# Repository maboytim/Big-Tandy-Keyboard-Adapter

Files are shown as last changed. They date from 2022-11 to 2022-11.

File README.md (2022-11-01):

# Big-Tandy-Keyboard-Adapter
PS2 keyboard adapter for 'Big Tandy' computers - Models II, 12, 16, 16B, and 6000.

The keyboard allows you to use a PS2 keyboard with your 'Big Tandy' computer.  There are three versions:

### "A" Version
The A version is for the Models II and 16.  These models have the keyboard cable attached to the computer.  The adapter connects to the end of the cable and the PS2 keyboard to the adapter.

### "B" Version
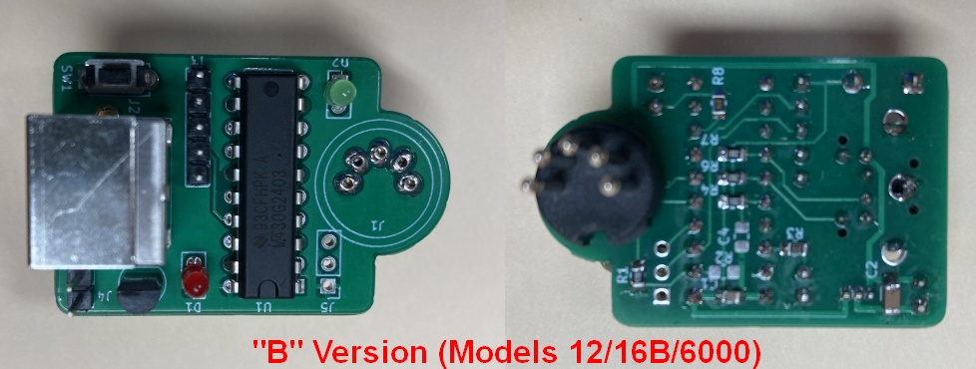
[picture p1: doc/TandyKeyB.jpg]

The B version is for the Models 12, 16B, and 6000.  These models have the keyboard cable attached to the computer.  The adapter plugs directly into the keyboard plug on the front of the computer and the PS2 keyboard into the adapter.

### "AB" Version (universal)
The AB version is for all models.  It has a 5-pin header to connect a pigtail cable.  A pigtail with a male DIN5 connector for Models 12/16B/6000 or a pigtail with a female DIN5 connector for Models II/16.  The pinout differences are also accounted for in the pigtail cable.

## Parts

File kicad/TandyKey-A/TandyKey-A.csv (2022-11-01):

Source: | C:\Users\matt\Documents\KiCad\6.0\TRS-80-M3-KEY\TRS-80-M3-KEY.kicad_sch
Date: | 8/21/2022 6:23:56 AM
Tool: | Eeschema (6.0.0)
Generator: | C:\Program Files\KiCad\6.0\bin\scripting\plugins/bom_csv_grouped_by_value.py
Component Count: | 32
Individual Components:
Item | Qty | Reference(s) | Value | LibPart | Footprint | Datasheet
 |  | C1 | 0.1uF | Device:C | Capacitor_SMD:C_0805_2012Metric_Pad1.18x1.45mm_HandSolder | ~
 |  | C2 | 0.1uF | Device:C | Capacitor_SMD:C_0805_2012Metric_Pad1.18x1.45mm_HandSolder | ~
 |  | C3 | 0.1uF | Device:C | Capacitor_SMD:C_0805_2012Metric_Pad1.18x1.45mm_HandSolder | ~
 |  | C6 | 10u | Device:C_Polarized | Capacitor_SMD:C_1206_3216Metric_Pad1.33x1.80mm_HandSolder | ~
 |  | C7 | 10u | Device:C_Polarized | Capacitor_SMD:C_1206_3216Metric_Pad1.33x1.80mm_HandSolder | ~
 |  | C8 | 10u | Device:C_Polarized | Capacitor_SMD:C_1206_3216Metric_Pad1.33x1.80mm_HandSolder | ~
 |  | H1 | MountingHole | Mechanical:MountingHole | MountingHole:MountingHole_3mm_Pad_Via | ~
 |  | H2 | MountingHole | Mechanical:MountingHole | MountingHole:MountingHole_3mm_Pad_Via | ~
 |  | H3 | MountingHole | Mechanical:MountingHole | MountingHole:MountingHole_3mm_Pad_Via | ~
 |  | H4 | MountingHole | Mechanical:MountingHole | MountingHole:MountingHole_3mm_Pad_Via | ~
 |  | J1 | Keyboard | Connector_Generic:Conn_02x10_Odd_Even | Connector_PinHeader_2.54mm:PinHeader_2x10_P2.54mm_Vertical | ~
 |  | J2 | Conn_01x06_Male | Connector:Conn_01x06_Male | Connector_PinHeader_2.54mm:PinHeader_1x06_P2.54mm_Horizontal | ~
 |  | J3 | Mini-DIN-6 | Connector:Mini-DIN-6 | TRS-80:minidin_6_ps2_pcb_mount | http://service.powerdynamics.com/ec/Catalog17/Section%2011.pdf
 |  | J4 | VGA | Connector:DB15_Female_HighDensity | TRS-IO-M1:DB_15F-VGA | ~
 |  | J5 | Test | conn:Conn_01x02 | Connector_PinHeader_2.54mm:PinHeader_1x02_P2.54mm_Vertical
 |  | J6 | Power | conn:Conn_01x02 | Connector_PinHeader_2.54mm:PinHeader_1x02_P2.54mm_Vertical
 |  | Q1 | 2N2702 | Device:Q_NMOS_GSD | Package_TO_SOT_SMD:SOT-23 | ~
 |  | R1 | 200 | Device:R | Resistor_SMD:R_0805_2012Metric_Pad1.20x1.40mm_HandSolder | ~
 |  | R2 | 200 | Device:R | Resistor_SMD:R_0805_2012Metric_Pad1.20x1.40mm_HandSolder | ~
 |  | R3 | 200 | Device:R | Resistor_SMD:R_0805_2012Metric_Pad1.20x1.40mm_HandSolder | ~
 |  | R4 | 200 | Device:R | Resistor_SMD:R_0805_2012Metric_Pad1.20x1.40mm_HandSolder | ~
 |  | R5 | 200 | Device:R | Resistor_SMD:R_0805_2012Metric_Pad1.20x1.40mm_HandSolder | ~
 |  | R6 | 2K | Device:R | Resistor_SMD:R_0805_2012Metric_Pad1.20x1.40mm_HandSolder | ~
 |  | R7 | 2K | Device:R | Resistor_SMD:R_0805_2012Metric_Pad1.20x1.40mm_HandSolder | ~
 |  | R8 | 10k | Device:R | Resistor_SMD:R_0805_2012Metric_Pad1.20x1.40mm_HandSolder | ~
 |  | R9 | 10k | Device:R | Resistor_SMD:R_0805_2012Metric_Pad1.20x1.40mm_HandSolder | ~
 |  | R10 | 10k | Device:R | Resistor_SMD:R_0805_2012Metric_Pad1.20x1.40mm_HandSolder | ~
 |  | RP1 | R 1kx8 | Connector_Generic:Conn_01x09 | Connector_PinSocket_2.54mm:PinSocket_1x09_P2.54mm_Vertical | ~
 |  | U1 | Tango_Nano_9K | MYLIB:Tango_Nano_9K | TRS-IO-M1:DIP-48_W22.9mm
 |  | U2 | SN74LVCH8T245 | MYLIB:SN74LVCH8T245 | Package_SO:TSSOP-24_4.4x7.8mm_P0.65mm
 |  | U3 | 74LVC125 | 74xx:74LS125 | Package_SO:SO-14_3.9x8.65mm_P1.27mm | http://www.ti.com/lit/gpn/sn74LS125
 |  | U5 | LD1117DT18TR | MYLIB:LD1117DT18TR | Package_TO_SOT_SMD:TO-252-3_TabPin2
Collated Components:
Item | Qty | Reference(s) | Value | LibPart | Footprint | Datasheet
1 | 3 | C1, C2, C3 | 0.1uF | Device:C | Capacitor_SMD:C_0805_2012Metric_Pad1.18x1.45mm_HandSolder | ~
2 | 3 | C6, C7, C8 | 10u | Device:C_Polarized | Capacitor_SMD:C_1206_3216Metric_Pad1.33x1.80mm_HandSolder | ~
3 | 4 | H1, H2, H3, H4 | MountingHole | Mechanical:MountingHole | MountingHole:MountingHole_3mm_Pad_Via | ~
4 | 1 | J1 | Keyboard | Connector_Generic:Conn_02x10_Odd_Even | Connector_PinHeader_2.54mm:PinHeader_2x10_P2.54mm_Vertical | ~
5 | 1 | J2 | Conn_01x06_Male | Connector:Conn_01x06_Male | Connector_PinHeader_2.54mm:PinHeader_1x06_P2.54mm_Horizontal | ~
6 | 1 | J3 | Mini-DIN-6 | Connector:Mini-DIN-6 | TRS-80:minidin_6_ps2_pcb_mount | http://service.powerdynamics.com/ec/Catalog17/Section%2011.pdf
7 | 1 | J4 | VGA | Connector:DB15_Female_HighDensity | TRS-IO-M1:DB_15F-VGA | ~
8 | 1 | J5 | Test | conn:Conn_01x02 | Connector_PinHeader_2.54mm:PinHeader_1x02_P2.54mm_Vertical
9 | 1 | J6 | Power | conn:Conn_01x02 | Connector_PinHeader_2.54mm:PinHeader_1x02_P2.54mm_Vertical
10 | 1 | Q1 | 2N2702 | Device:Q_NMOS_GSD | Package_TO_SOT_SMD:SOT-23 | ~
11 | 5 | R1, R2, R3, R4, R5 | 200 | Device:R | Resistor_SMD:R_0805_2012Metric_Pad1.20x1.40mm_HandSolder | ~
12 | 2 | R6, R7 | 2K | Device:R | Resistor_SMD:R_0805_2012Metric_Pad1.20x1.40mm_HandSolder | ~
13 | 3 | R8, R9, R10 | 10k | Device:R | Resistor_SMD:R_0805_2012Metric_Pad1.20x1.40mm_HandSolder | ~
14 | 1 | RP1 | R 1kx8 | Connector_Generic:Conn_01x09 | Connector_PinSocket_2.54mm:PinSocket_1x09_P2.54mm_Vertical | ~
15 | 1 | U1 | Tango_Nano_9K | MYLIB:Tango_Nano_9K | TRS-IO-M1:DIP-48_W22.9mm
16 | 1 | U2 | SN74LVCH8T245 | MYLIB:SN74LVCH8T245 | Package_SO:TSSOP-24_4.4x7.8mm_P0.65mm
17 | 1 | U3 | 74LVC125 | 74xx:74LS125 | Package_SO:SO-14_3.9x8.65mm_P1.27mm | http://www.ti.com/lit/gpn/sn74LS125
18 | 1 | U5 | LD1117DT18TR | MYLIB:LD1117DT18TR | Package_TO_SOT_SMD:TO-252-3_TabPin2

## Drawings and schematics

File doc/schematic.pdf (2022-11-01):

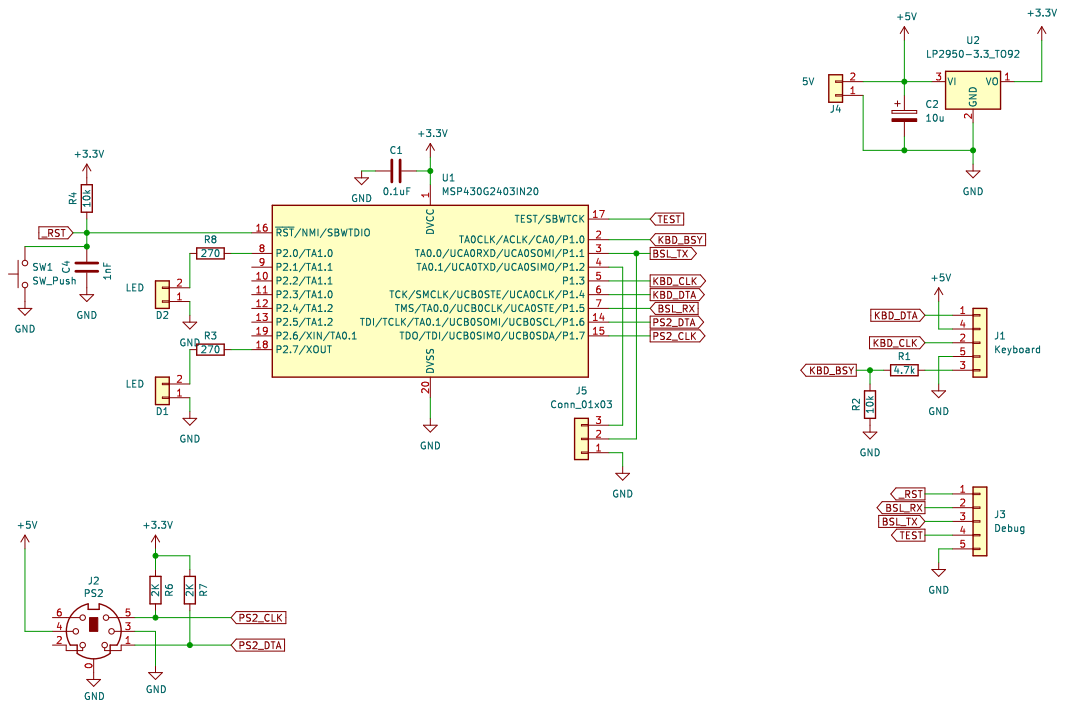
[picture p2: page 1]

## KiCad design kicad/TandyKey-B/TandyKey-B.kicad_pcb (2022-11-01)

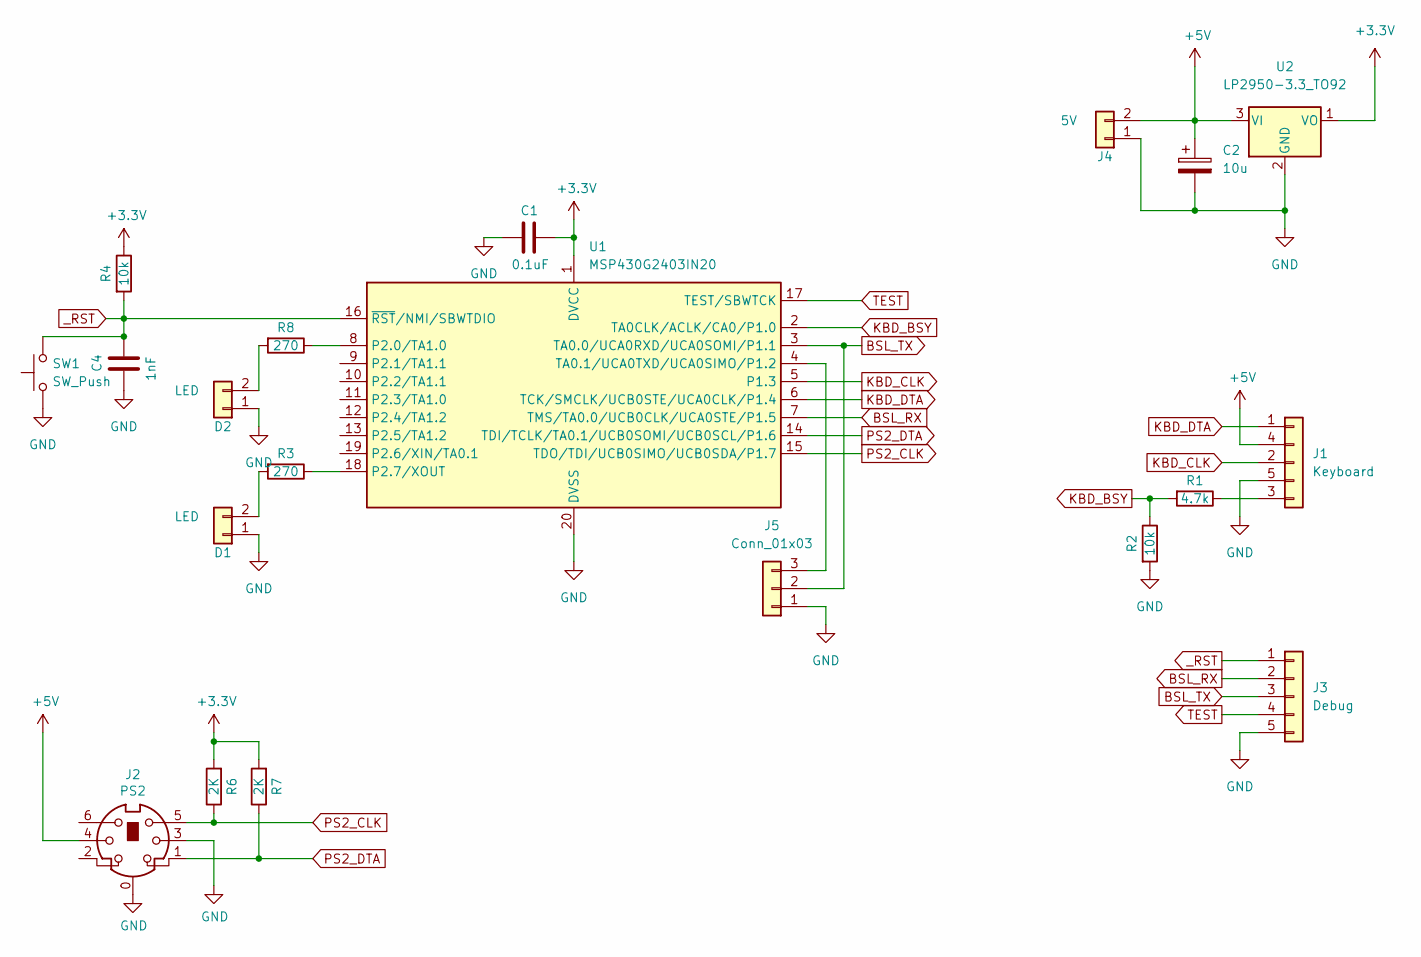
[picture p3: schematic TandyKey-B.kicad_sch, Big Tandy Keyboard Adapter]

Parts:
C1: 0.1uF; C_0805_2012Metric_Pad1.18x1.45mm_HandSolder
C2: 10u; C_1206_3216Metric_Pad1.33x1.80mm_HandSolder
C4: 1nF; C_0805_2012Metric_Pad1.18x1.45mm_HandSolder
D1, D2: LED; PinHeader_1x02_P2.54mm_Vertical
J1: Keyboard; DIN5
J2: PS2; minidin_6_ps2_pcb_mount
J3: Debug; PinHeader_1x05_P2.54mm_Vertical
J4: 5V; PinHeader_1x02_P2.54mm_Vertical
J5: Conn_01x03; PinHeader_1x03_P2.54mm_Vertical
R1: 4.7k; R_0805_2012Metric_Pad1.20x1.40mm_HandSolder
R2, R4: 10k; R_0805_2012Metric_Pad1.20x1.40mm_HandSolder
R3, R8: 270; R_0805_2012Metric_Pad1.20x1.40mm_HandSolder
R6, R7: 2K; R_0805_2012Metric_Pad1.20x1.40mm_HandSolder
SW1: SW_Push; PinHeader_1x02_P2.54mm_Vertical
U1: MSP430G2403IN20; DIP-20_W7.62mm
U2: LP2950-3.3_TO92; TO-92_Inline

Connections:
+3V3: C1.1, R4.1, R6.2, R7.2, U1.1 (DVCC), U2.1 (VO)
+5V: C2.1, J1.4, J2.4, J4.2, U2.3 (VI)
BSL_RX: J3.2, U1.7 (TMS/TA0.0/UCB0CLK/UCA0STE/P1.5)
BSL_TX: J3.3, J5.2, U1.3 (TA0.0/UCA0RXD/UCA0SOMI/P1.1)
GND: C1.2, C2.2, C4.2, D1.1, D2.1, J1.5, J2.0, J2.3, J3.5, J4.1, J5.1, R2.2, SW1.1, U1.20 (DVSS), U2.2 (GND)
KBD_BSY: R1.2, R2.1, U1.2 (TA0CLK/ACLK/CA0/P1.0)
KBD_CLK: J1.2, U1.5 (P1.3)
KBD_DTA: J1.1, U1.6 (TCK/SMCLK/UCB0STE/UCA0CLK/P1.4)
unnamed: D1.2, R3.2
unnamed: D2.2, R8.2
unnamed: J1.3, R1.1
unnamed: J5.3, U1.4 (TA0.1/UCA0TXD/UCA0SIMO/P1.2)
unnamed: R3.1, U1.18 (P2.7/XOUT)
unnamed: R8.1, U1.8 (P2.0/TA1.0)
PS2_CLK: J2.5, R6.1, U1.15 (TDO/TDI/UCB0SIMO/UCB0SDA/P1.7)
PS2_DTA: J2.1, R7.1, U1.14 (TDI/TCLK/TA0.1/UCB0SOMI/UCB0SCL/P1.6)
TEST: J3.4, U1.17 (TEST/SBWTCK)
_RST: C4.1, J3.1, R4.2, SW1.2, U1.16 (~RST/NMI/SBWTDIO)

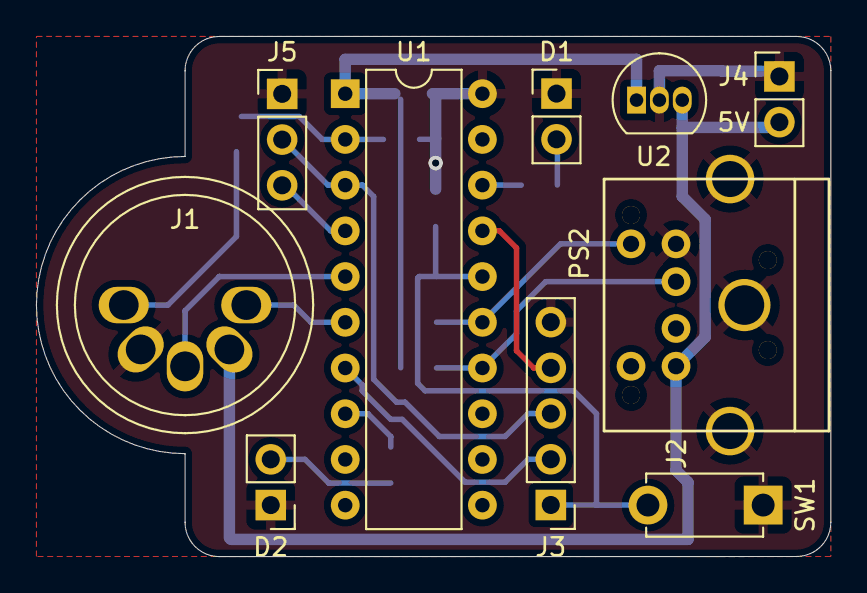
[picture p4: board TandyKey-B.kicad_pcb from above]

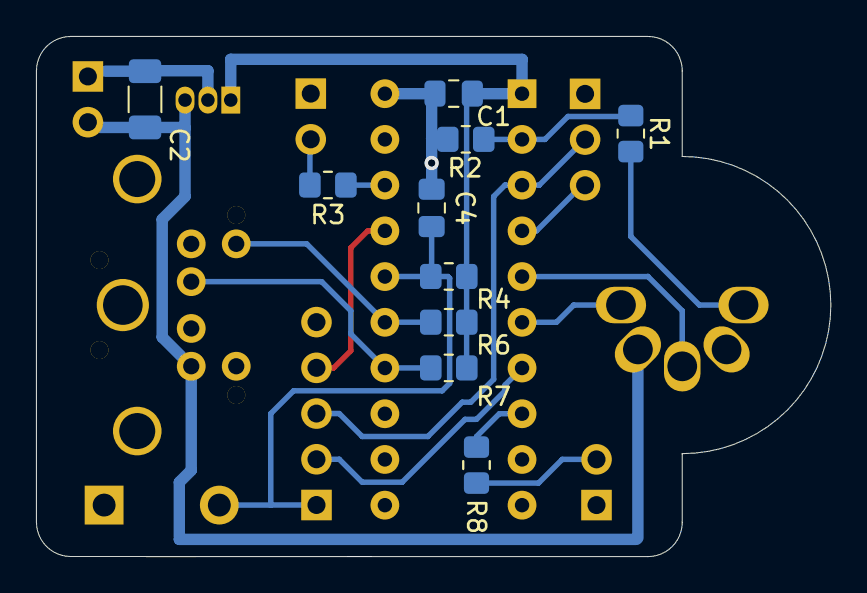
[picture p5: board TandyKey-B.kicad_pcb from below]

Board: 2 copper layers, 44.1 x 28.9 mm, 20 parts (10 on the bottom side), 18 nets.

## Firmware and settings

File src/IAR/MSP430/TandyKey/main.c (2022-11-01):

// Include the device header for the IAR processor setting
#include <msp430.h>
#include <stdint.h>

// Set to 0 to disable watchdog timer, set to 1 to enable.
#define USE_WDT  1

// IO bit assignments
// P1
// Tandy keyboard (output)
#define KBD_BSYN BIT0  // input
#define KBD_CLK  BIT3  // output
#define KBD_DTA  BIT4  // output

// PS2 keyboard (input)
#define PS2_DTA  BIT6  // input
#define PS2_CLK  BIT7  // input

// UART (input/output)
#define UART_RX  BIT1  // input (also BSL_TX)
#define UART_TX  BIT2  // output

// BSL
// used by bootstrap loader
#define BSL_TX   BIT1
#define BSL_RX   BIT5

// P2
// LED's
#define LED1     BIT0  // output
#define LED0     BIT7  // output

// Output bit rate
// The PS2 clock is between 10 kHz and 16.7 kHz.  The baud specified here is baud of
// the output keyboard clock.  This doesn't have to be a standard baud nor does it
// have to conform to the PS2 clock requirement, but the characters are also output
// in UART format so a standard baud within the PS2 range is used.  For the Tandy
// serial format it is convenient to use a 4x clock so 14.4k might be approaching
// the practical maximum for an 8MHz cpu clock.  The cpu can run at 16MHz though so
// this could be increased if the cpu clock is increased.
#define BAUD     14400L

// Timer period for 4*baud clock
#define PERIOD0  (8000000L/(BAUD*4L))  // 8MHz cpu

volatile uint8_t ps2_hld;
volatile uint8_t ps2_hld_rdy = 0;

#define KBD_BUF_N  16  // must be power of 2
volatile uint8_t kbd_buf[KBD_BUF_N];
uint8_t kbd_buf_in;
volatile uint8_t kbd_buf_out;

const struct
   {
   uint16_t code;
   uint8_t  ctrl;
   uint8_t  shft;
   uint8_t  alt;
   uint8_t  none;
   } ps2_map[] =
   {
      // [0..25]
      // for A-Z the CapsLock swaps the shift and none columns
      // code, ctrl, shft,  alt, none,
      { 0x01c, 0x01, 0x41, 0xc1, 0x61, }, // A
      { 0x032, 0x02, 0x42, 0xc2, 0x62, }, // B
      { 0x021, 0x03, 0x43, 0xc3, 0x63, }, // C
      { 0x023, 0x04, 0x44, 0xc4, 0x64, }, // D
      { 0x024, 0x05, 0x45, 0xc5, 0x65, }, // E
      { 0x02b, 0x06, 0x46, 0xc6, 0x66, }, // F
      { 0x034, 0x07, 0x47, 0xc7, 0x67, }, // G
      { 0x033, 0x08, 0x48, 0xc8, 0x68, }, // H
      { 0x043, 0x09, 0x49, 0xc9, 0x69, }, // I
      { 0x03b, 0x0a, 0x4a, 0xca, 0x6a, }, // J
      { 0x042, 0x0b, 0x4b, 0xcb, 0x6b, }, // K
      { 0x04b, 0x0c, 0x4c, 0xcc, 0x6c, }, // L
      { 0x03a, 0x0d, 0x4d, 0xcd, 0x6d, }, // M
      { 0x031, 0x0e, 0x4e, 0xce, 0x6e, }, // N
      { 0x044, 0x0f, 0x4f, 0xcf, 0x6f, }, // O
      { 0x04d, 0x10, 0x50, 0xd0, 0x70, }, // P
      { 0x015, 0x11, 0x51, 0xd1, 0x71, }, // Q
      { 0x02d, 0x12, 0x52, 0xd2, 0x72, }, // R
      { 0x01b, 0x13, 0x53, 0xd3, 0x73, }, // S
      { 0x02c, 0x14, 0x54, 0xd4, 0x74, }, // T
      { 0x03c, 0x15, 0x55, 0xd5, 0x75, }, // U
      { 0x02a, 0x16, 0x56, 0xd6, 0x76, }, // V
      { 0x01d, 0x17, 0x57, 0xd7, 0x77, }, // W
      { 0x022, 0x18, 0x58, 0xd8, 0x78, }, // X
      { 0x035, 0x19, 0x59, 0xd9, 0x79, }, // Y
      { 0x01a, 0x1a, 0x5a, 0xda, 0x7a, }, // Z

      // [26..30]
      // code, ctrl, shft,  alt, none,
      { 0x05a, 0x0d, 0x0d, 0x0d, 0x0d, }, // ENTER
      { 0x029, 0x20, 0x20, 0x20, 0x20, }, // SPACE
      { 0x066, 0x08, 0x08, 0x08, 0x08, }, // BACKSPACE
      { 0x00d, 0x09, 0x09, 0x09, 0x09, }, // TAB
      { 0x076, 0x1b, 0x1b, 0x1b, 0x1b, }, // ESC

      // [31..40]
      { 0x045, 0x7c, 0x29, 0xb0, 0x30, }, // 0 )
      { 0x016, 0xa1, 0x21, 0xb1, 0x31, }, // 1 !
      { 0x01e, 0xc0, 0x40, 0xb2, 0x32, }, // 2 @
      { 0x026, 0xa3, 0x23, 0xb3, 0x33, }, // 3 #
      { 0x025, 0xa4, 0x24, 0xb4, 0x34, }, // 4 $
      { 0x02e, 0xa5, 0x25, 0xb5, 0x35, }, // 5 %
      { 0x036, 0x7e, 0x5e, 0xb6, 0x36, }, // 6 ^
      { 0x03d, 0xa6, 0x26, 0xb7, 0x37, }, // 7 &
      { 0x03e, 0xaa, 0x2a, 0xb8, 0x38, }, // 8 *
      { 0x046, 0x5c, 0x28, 0xb9, 0x39, }, // 9 (

      // [41..47]
      // code, ctrl, shft,  alt, none,
      { 0x052, 0xa2, 0x22, 0xa7, 0x27, }, // ' "
      { 0x041, 0xbc, 0x3c, 0xac, 0x2c, }, // , <
      { 0x04e, 0x7f, 0x5f, 0xad, 0x2d, }, // - _
      { 0x049, 0xbe, 0x3e, 0xae, 0x2e, }, // . >
      { 0x04a, 0xbf, 0x3f, 0xaf, 0x2f, }, // / ?
      { 0x04c, 0xba, 0x3a, 0xbb, 0x3b, }, // ; :
      { 0x055, 0xab, 0x2b, 0xbd, 0x3d, }, // = +

      // [48..50]
      // code, ctrl, shft,  alt, none,
      { 0x054, 0xdb, 0x7b, 0xfb, 0x5b, }, // [ {
      { 0x05d, 0xdc, 0x7c, 0xfc, 0x5c, }, // \ |
      { 0x05b, 0xdd, 0x7d, 0xfd, 0x5d, }, // ] }

      // [51..66]
      // code, ctrl, shft,  alt, none,
      { 0x070, 0x30, 0x30, 0x30, 0x30, }, // kp 0
      { 0x069, 0x31, 0x31, 0x31, 0x31, }, // kp 1
      { 0x072, 0x32, 0x32, 0x32, 0x32, }, // kp 2
      { 0x07a, 0x33, 0x33, 0x33, 0x33, }, // kp 3
      { 0x06b, 0x34, 0x34, 0x34, 0x34, }, // kp 4
      { 0x073, 0x35, 0x35, 0x35, 0x35, }, // kp 5
      { 0x074, 0x36, 0x36, 0x36, 0x36, }, // kp 6
      { 0x06c, 0x37, 0x37, 0x37, 0x37, }, // kp 7
      { 0x075, 0x38, 0x38, 0x38, 0x38, }, // kp 8
      { 0x07d, 0x39, 0x39, 0x39, 0x39, }, // kp 9
      { 0x07c, 0x2a, 0x2a, 0x2a, 0x2a, }, // kp *
      { 0x079, 0x2b, 0x2b, 0x2b, 0x2b, }, // kp +
      { 0x07b, 0x2d, 0x2d, 0x2d, 0x2d, }, // kp -
      { 0x071, 0x2e, 0x2e, 0x2e, 0x2e, }, // kp .
      { 0x14a, 0x2f, 0x2f, 0x2f, 0x2f, }, // kp /
      { 0x15a, 0x0d, 0x0d, 0x0d, 0x0d, }, // kp ENTER

      // [67..70]
      // code, ctrl, shft,  alt, none,
      { 0x16b, 0x1c, 0x1c, 0x1c, 0x1c, }, // LEFT ARROW
      { 0x174, 0x1d, 0x1d, 0x1d, 0x1d, }, // RIGHT ARROW
      { 0x175, 0x1e, 0x1e, 0x1e, 0x1e, }, // UP ARROW
      { 0x172, 0x1f, 0x1f, 0x1f, 0x1f, }, // DOWN ARROW

      // [71..72]
      // code, ctrl, shft,  alt, none,
      { 0x169, 0x03, 0x03, 0x03, 0x03, }, // END (->BREAK)
      { 0x07e, 0x00, 0x00, 0x00, 0x00, }, // SCROLL
#define F10_IDX  73 // index of F10 in the table
      // [73..82]
      // for alt-F10-F9 a second byte of '0'-'9' is output
      // code, ctrl, shft,  alt, none,
      { 0x009, 0x00, 0x00, 0xfc, 0x00, }, // F10
      { 0x005, 0x01, 0x01, 0xfc, 0x01, }, // F1
      { 0x006, 0x02, 0x02, 0xfc, 0x02, }, // F2
      { 0x004, 0x04, 0x04, 0xfc, 0x04, }, // F3
      { 0x00c, 0x0c, 0x0c, 0xfc, 0x0c, }, // F4
      { 0x003, 0x15, 0x15, 0xfc, 0x15, }, // F5
      { 0x00b, 0x10, 0x10, 0xfc, 0x10, }, // F6
      { 0x083, 0x0e, 0x0e, 0xfc, 0x0e, }, // F7
      { 0x00a, 0x13, 0x13, 0xfc, 0x13, }, // F8
      { 0x001, 0x1a, 0x1a, 0xfc, 0x1a, }, // F9
   };

uint8_t ps2_caps = 0;


void main(void)
   {
   __disable_interrupt();
#if USE_WDT
   WDTCTL = WDTPW + WDTCNTCL;
#else
   // Stop watchdog timer
   WDTCTL = WDTPW + WDTHOLD;
#endif

   // Calibrate the clock for 8MHz
   DCOCTL = 0;
#if 1
   BCSCTL1 = CALBC1_8MHZ != 0xFF ? CALBC1_8MHZ : 0x8d;
   DCOCTL  = CALDCO_8MHZ != 0xFF ? CALDCO_8MHZ : 0x58;
#else
   BCSCTL1 = CALBC1_8MHZ;
   DCOCTL  = CALDCO_8MHZ;
#endif
   P2SEL = 0x00;

   // Configure and initialize ports
#if 0
   // enable pullups on ps2 clk and dta and uart rx
   // enable pulldown on keyboard busy
   // output keyboard dta high, uart tx high
   // output keyboard clock low
   P1OUT = PS2_CLK | PS2_DTA | KBD_DTA | UART_TX | UART_RX;
#else
   // enable pullups on ps2 clk, dta and keyboard busy and uart rx
   // output keyboard dta high, uart tx high
   // output keyboard clock low
   P1OUT = PS2_CLK | PS2_DTA | KBD_BSYN | KBD_DTA | UART_TX | UART_RX;
#endif
   P1REN = PS2_CLK | PS2_DTA | KBD_BSYN | UART_RX;
   P1DIR = KBD_CLK | KBD_DTA | UART_TX;  // keyboard clk and dta outputs
   P1IES = PS2_CLK;  // falling edge
   P1IE  = PS2_CLK;

   // Initialize LED0 off, LED1 on
   P2OUT = LED1;
   P2DIR = LED0 | LED1;

   // Initialize the timer - channel0 for the keyboard bit rate
   TACCR0 = PERIOD0 - 1; // Up mode counts to TACCR9
   TACTL = TACLR | TASSEL_2 | MC_1 | TAIE; // Set the timer A to SMCLCK, Up mode, Overflow interrupt

   // Enable global interrupts
   __enable_interrupt();

   uint8_t ps2_dta = 0, prev_ps2_dta = 0, prev_prev_ps2_dta = 0;
   uint8_t ps2_shft = 0, ps2_ctrl = 0, ps2_alt = 0;
   while(1)
      {
#if USE_WDT
      WDTCTL = WDTPW + WDTCNTCL;
#endif

      if(ps2_hld_rdy)
         {
         prev_prev_ps2_dta = prev_ps2_dta;
         prev_ps2_dta = ps2_dta;
         ps2_dta = ps2_hld;
         ps2_hld_rdy = 0;

         if(!(ps2_dta == 0xf0 || ps2_dta == 0xe0))
            {
            uint8_t ps2_esc = (prev_ps2_dta == 0xf0) ? (prev_prev_ps2_dta == 0xe0) : (prev_ps2_dta == 0xe0);
            uint16_t ps2_esc_dta = (ps2_esc << 8) | ps2_dta;
            uint8_t ps2_release = (prev_ps2_dta == 0xf0);
            if(!ps2_release)
               {
               uint8_t ps2_code = 0;
               uint8_t ps2_code_rdy = 0;
               uint16_t i;

               for(i = 0; i < sizeof(ps2_map)/sizeof(ps2_map[0]); i++)
                  {
                  if(ps2_esc_dta == ps2_map[i].code)
                     {
                     ps2_code = ps2_ctrl ? ps2_map[i].ctrl : ps2_alt ? ps2_map[i].alt : ps2_shft ? ((i < 26 && (ps2_caps & 1)) ? ps2_map[i].none : ps2_map[i].shft)
                                                                                                 : ((i < 26 && (ps2_caps & 1)) ? ps2_map[i].shft : ps2_map[i].none);
                     ps2_code_rdy = 1;
                     break;
                     }
                  }
               if(ps2_code_rdy)
                  {
                  uint8_t tmp_buf_in = kbd_buf_in;
                  kbd_buf[tmp_buf_in] = ps2_code;
                  tmp_buf_in = (tmp_buf_in + 1) & (KBD_BUF_N - 1);
                  if(tmp_buf_in != kbd_buf_out)
                     {
                     if(i >= F10_IDX && i < F10_IDX + 10 && ps2_code == 0xfc)
                        {
                        kbd_buf[tmp_buf_in] = '0' + (i - F10_IDX);
                        tmp_buf_in = (tmp_buf_in + 1) & (KBD_BUF_N - 1);
                        if(tmp_buf_in != kbd_buf_out)
                           kbd_buf_in = tmp_buf_in;
                        }
                     else
                        kbd_buf_in = tmp_buf_in;
                     }
                  }
               else
                  {
                  if(ps2_esc_dta == 0x012) // LEFT SHIFT
                     ps2_shft |= 1;
                  else if(ps2_esc_dta == 0x059) // RIGHT SHIFT
                     ps2_shft |= 2;
                  else if(ps2_esc_dta == 0x014) // LEFT CTRL
                     ps2_ctrl |= 1;
                  else if(ps2_esc_dta == 0x114) // RIGHT CTRL
                     ps2_ctrl |= 2;
                  else if(ps2_esc_dta == 0x011) // LEFT ALT
                     ps2_alt  |= 1;
                  else if(ps2_esc_dta == 0x111) // RIGHT ALT
                     ps2_alt  |= 2;
                  else if(ps2_esc_dta == 0x058) // CAPS
                     ps2_caps = 2 | ((ps2_caps >> 1) ^ 1 ^ ps2_caps);
                  }
               }
            else
               {
               if(ps2_esc_dta == 0x012) // LEFT SHIFT
                  ps2_shft &= 2;
               else if(ps2_esc_dta == 0x059) // RIGHT SHIFT
                  ps2_shft &= 1;
               else if(ps2_esc_dta == 0x014) // LEFT CTRL
                  ps2_ctrl &= 2;
               else if(ps2_esc_dta == 0x114) // RIGHT CTRL
                  ps2_ctrl &= 1;
               else if(ps2_esc_dta == 0x011) // LEFT ALT
                  ps2_alt  &= 2;
               else if(ps2_esc_dta == 0x111) // RIGHT ALT
                  ps2_alt  &= 1;
               else if(ps2_esc_dta == 0x058) // CAPS
                  ps2_caps &= 1;
               }
            }
         }
      }
   }


// Timer A0 interrupt service routine
#pragma vector=TIMER0_A0_VECTOR
__interrupt void Timer_A0 (void)
   {
   while(1)
      {
      }
   }

// Timer A1 interrupt service routine (shared interrupt)
#pragma vector=TIMER0_A1_VECTOR
__interrupt void Timer_A1 (void)
   {
   static uint8_t kbd_state = 0;
   static uint8_t kbd_shr;
   static uint16_t div = BAUD*2L - 1;  // 1/2 second
   TAIV;

   if(kbd_state == 0)
      {
      // if character is ready in fifo and computer is ready then send next character
      if(kbd_buf_out != kbd_buf_in && (P1IN & KBD_BSYN))
         {
         kbd_shr = kbd_buf[kbd_buf_out];
         kbd_buf_out = (kbd_buf_out + 1) & (KBD_BUF_N - 1);
         P1OUT &= ~UART_TX;  // output start bit
         P2OUT |= LED1;
         ++kbd_state;
         }
      }
   else if(kbd_state < 4)
      {
      // delay for tandy key out
      // start bit for uart out
      ++kbd_state;
      }
   else
      {
      // the 8 data bits are output for states 4-7, 8-11, ..., 32-35
      // states 36-39 are end of data pulse for tandy key out
      // states 36-39 are stop bit for uart out
      switch(kbd_state & 3)
         {
         case 0:
            if(kbd_state < 36)
               {
               // states 4-35 are data bits
               if(kbd_shr & 1)
                  {
                  P1OUT |= (KBD_DTA | UART_TX);
                  }
               else
                  {
                  P1OUT &= ~(KBD_DTA | UART_TX);
                  }
               kbd_shr >>= 1;
               }
            else
               {
               // states 36-39 are end of data pulse for tandy key out
               // states 36-39 are stop bit for uart out
               //P1OUT &= ~KBD_DTA;  // output low for beginning of end of data pulse
               //P1OUT |= UART_TX;  // output high for stop bit
               P1OUT = P1OUT & ~KBD_DTA | UART_TX;
               }
            break;
         case 1:
            // tandy key clock remains low during end of data pulse
            if(kbd_state < 36)
               P1OUT |= KBD_CLK;
            break;
         case 2:
            // output tandy key data high
            // this will latch the clock level into the end of data flipflop
            // if clock is high then this is data bit
            // if clock is low then this is end of data
            P1OUT |= KBD_DTA;
            break;
         case 3:
            // return clock low always
            P1OUT &= ~KBD_CLK;
            break;
         }

      if(!(++kbd_state < 40))
         {
         P2OUT &= ~LED1;
         kbd_state = 0;
         }
      }

   // toggle the led
   if(div-- == 0)
      {
      P2OUT ^= LED0;
      // slow toggle for capslock off
      // fast toggle for capslock on
      div = (ps2_caps & 1) ? (BAUD - 1) : (BAUD*2L - 1);
      }
   }

// Timer A1 interrupt service routine (shared interrupt)
#pragma vector=PORT1_VECTOR
__interrupt void Port1 (void)
   {
   static uint16_t ps2_shr = 0;
   P1IFG = 0x00;

   ps2_shr = (ps2_shr >> 1) | ((P1IN & PS2_DTA) ? 0 : 0x400);
   if(ps2_shr & 0x1)
      {
      if(!(ps2_shr & 0x400))
         {
         ps2_hld = (~ps2_shr) >> 1;
         ps2_hld_rdy = 1;
         }
      ps2_shr = 0;
      }
   }
